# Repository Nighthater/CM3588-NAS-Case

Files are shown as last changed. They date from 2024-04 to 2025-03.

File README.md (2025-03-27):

# CM3588 NAS Case
3D Printable Case for the CM3588 NAS board.  
Minimal Assembly required.  
Variants for Installations with fans are included.

If you have a fan, you can use [this code by vijaygill](https://github.com/vijaygill/pwm-fan-cm3588) to control the fans

### NOTE:
I do not have the NAS Board on Hand. If you decide to print the Case, please leave me some feedback to further improve the Case.  

The Case is [available for download](https://github.com/Nighthater/CM3588-NAS-Case/tree/master/STL).

## Required Components
- 4 M2 Threaded inserts
- 4 M2 Flat-Head Screws

Any Flat-Head screw is ok. Contersunk screws will damage the PCB, so avoid using these.  
The screw length must be smaller than 10mm.  

## Assembly

1. You need the three Parts of the Case and 5 buttons printed.
2. Begin by inserting the Threaded inserts in the 4 Standoff holes in the Main Body.
3. Place the 5 buttons inside the holes.
4. Insert the CM3588 Board into the Case. Keep it level when inserting. It should go in freely until it hits the standoffs.
5. Secure the PCB with the 4 Screws.
6. Attach the two Panels. The Panels are only using a friction fit currently. This might me improved in later revisions.
7. The NAS is ready to power up.

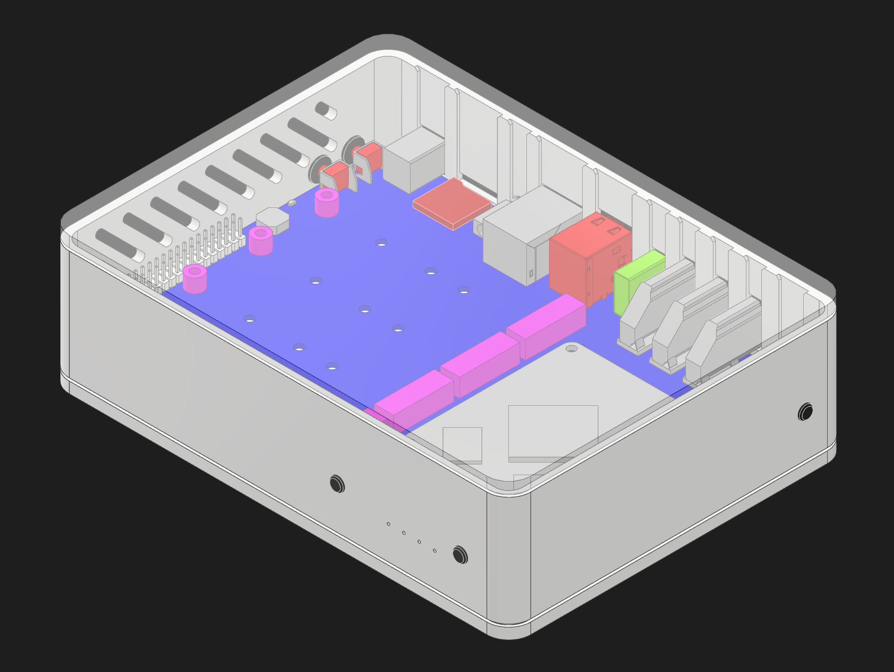
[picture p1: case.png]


## Internal Fan Variant
Also availible in a taller version with an internal fan. Uses a 80mm Noctua fan.
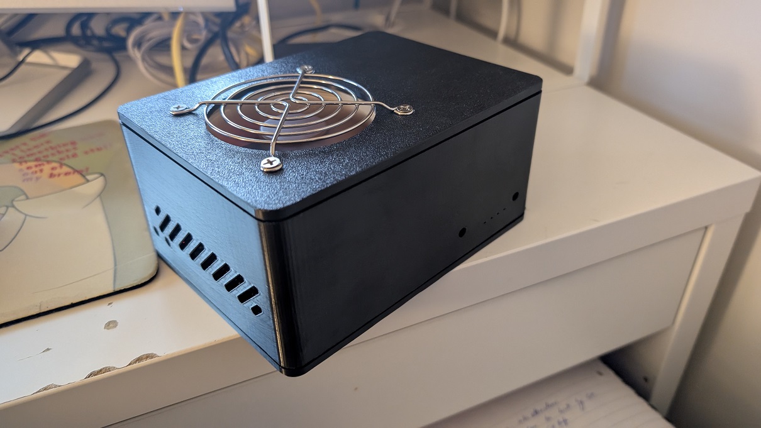
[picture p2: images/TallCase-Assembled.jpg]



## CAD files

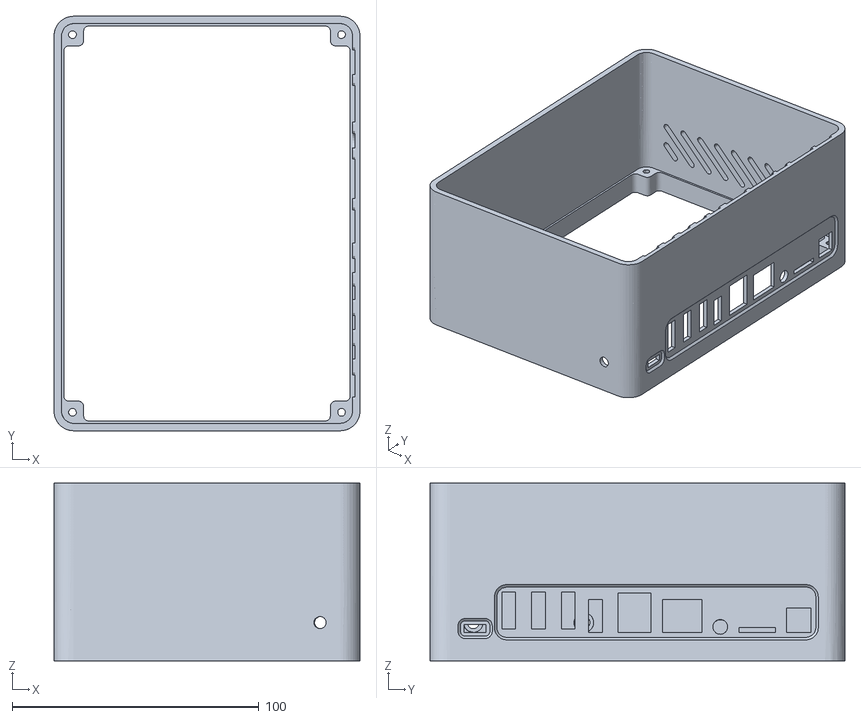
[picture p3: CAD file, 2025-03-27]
STL/MainBody - tall.stl
124.0 x 168.0 x 72.0

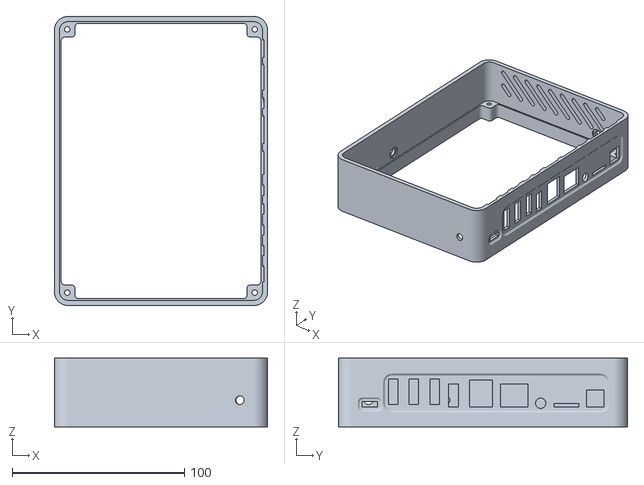
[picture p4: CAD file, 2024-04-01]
STL/MainBody.stl
124.0 x 168.0 x 40.0

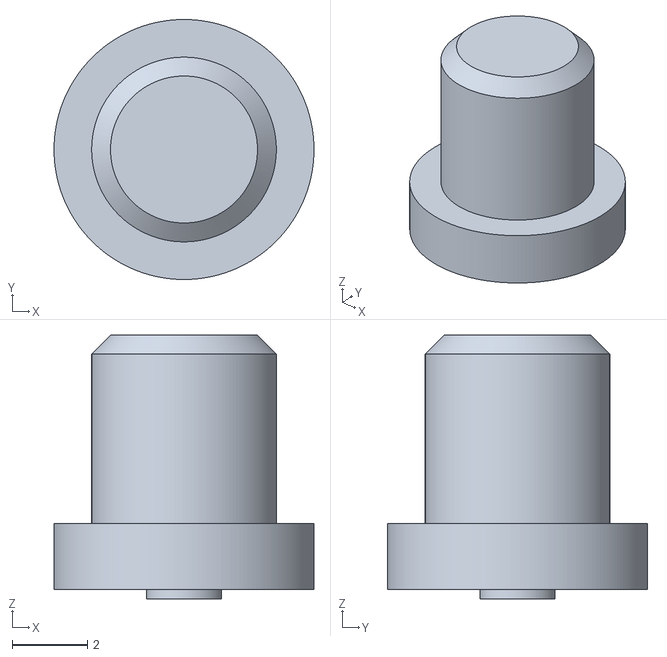
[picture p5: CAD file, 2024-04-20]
STL/Button.stl
6.90 x 6.90 x 7.00

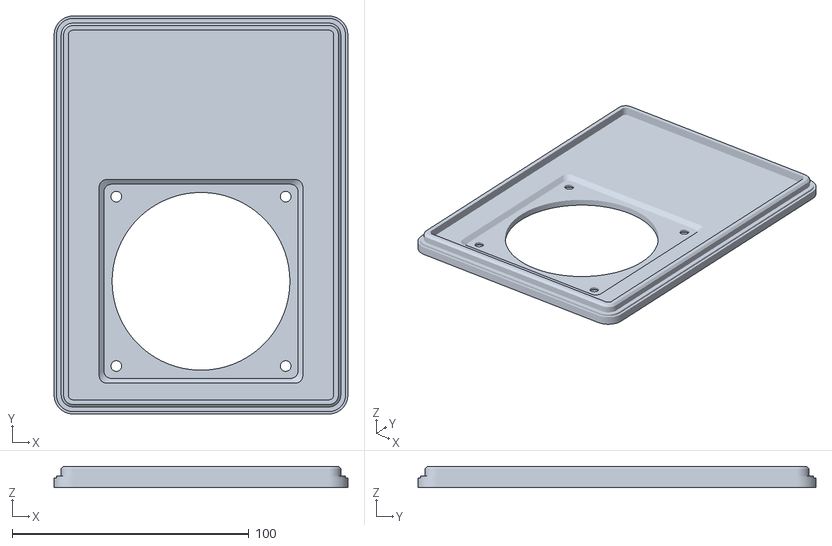
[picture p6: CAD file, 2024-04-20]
STL/TopShell_with_80mm_fan.stl
124.0 x 168.0 x 9.00

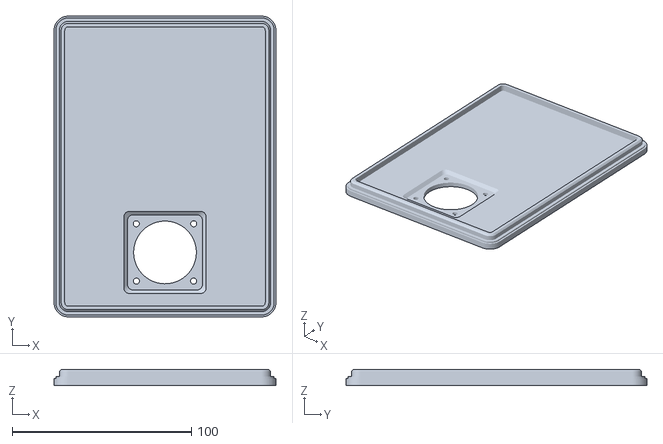
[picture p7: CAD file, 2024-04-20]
STL/TopShell_with_40mm_fan.stl
124.0 x 168.0 x 9.00

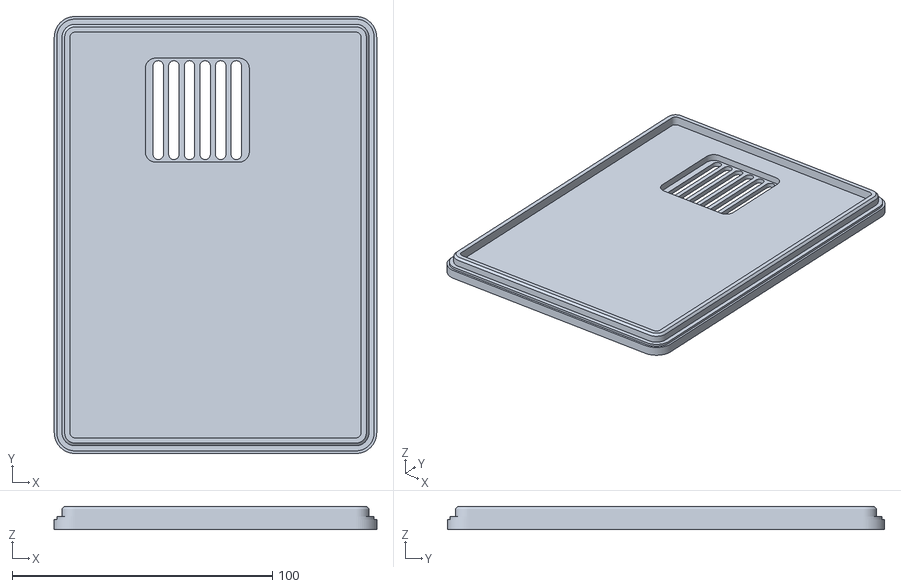
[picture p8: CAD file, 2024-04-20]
STL/TopShell_40mm_onboard_fan.stl
124.0 x 168.0 x 9.00

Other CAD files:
STL/TopShell.stl
STL/BottomShell.stl

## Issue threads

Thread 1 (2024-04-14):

Some adjustments

TurtleTony, 2024-04-14:
Hi there! First of all, thank you so much, the case is amazing :-) A friend of mine printed it for me with the following settings:

Printer: Anycubic Vyper
Slicer: Ultimaker Cura 5.2.2
Filament: Eryone White PLA 1,75 +- 0.03

0.16mm, 10% Infill, 200°C, 60.0mm/s

I've attached some pictures of how the board fits and firmly sits in the case. The screw-holes are somewhat misaligned, but I didn't even need the screws at all.

The slot for the sd card was a little too narrow so I had to sand it down a bit to get proper access to it. Otherwise all the I/O seems to be accessible to me.

An issue I had: The buttons don't work at all, they are a lot deeper than you'd think so they need to be at least 2mm longer to be able to use.

A feature idea: The heatsink has mounting holes for what I believe to be a 40mm fan, you could add an appropriate hole above this area to the lid, so that a fan could suck air from the lid and blow it out the side holes. I tried running the board cooled passively, but my SSDs got over 60 degree when utilized and had an idle temp of around 45-50°, that's not something to run 24/7 I feel like, so a fan hole would definitely add some more options.
Depending on the type of cable used, the case might benefit from slightly larger slots for the USB and HDMI connectors. Although sanding them down works too.

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

Nighthater, 2024-04-20:
Hi, thanks for the feedback. Glad that you like it so far.
I revised the Buttons and made them 2mm longer, they should be usable now.

The SD Card Reader Slot and the HDMI and USB ports are also now a bit bigger and should not require further sanding.

For the cooling issue, there are now three new lids. One with Holes to allow a 40mm fan mounted on the heatsink to pull in air.
The other two allow a 40mm or 80mm fan to be mounted directly on the lid.

TurtleTony, 2024-04-22:
Amazing! Thank you so much for the revisions! :-)
For cooling I actually went with laser-cutting a hole into the lid (but messed up and cut a square instead) so I mounted a fan to a glued on wood panel.

I will print the revised buttons and let you know how they work out :-)

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

mrjamesdoan, 2024-06-10:
I just came here to say thank you so much for creating this case. It works perfect for my needs and is very well designed. I'm impressed by the small details of the case and it seems to be better quality than the rest of available models out there. May I ask how you learned to design this? What tools did you use to design it and if you could point me to any resources that goes over how to design, specifically the rounded corners, indented inputs area, the raised mounts for the PCB and also the snap fit lids. It would be greatly appreciated!

Nighthater, 2024-06-11:
Hi, I'm glad you like the case. I made it with Autodesk Inventor, but you could design this case in probably any CAD Software you want (Fusion360 and OnShape are two popular free ones that come to mind).

I'm a mechanical engineer, so i've worked quite some time now with different CAD Software and how to design parts.
You can look at youtube tutorials and courses on how to use these CAD programs. Trying stuff out yourself is also important, even if its just a small simple part.

The snap fit lids are the same size and shape on both parts, just inside and outside, so its creating a transition fit.
For the design of the Case, I didn't really learn it how to do it i would say? It's more of creative process.
I tried to figure out how to build around the NAS Board itself while keeping all 4 sides accessible for the buttons and ports. That's why it's laid down from above, and that dictates the overall form of the case.
I also quite like the function first approach that Bauhaus Design takes (Rounded corners, straight lines, function over form). So theres an design style there you could look at.
Its also helpful for me to look at how different products are built from the inside in general. You can get lots of ideas to use in your own projects.

I hope i could help you, please feel free to ask if you have further questions.

Closed 2024-08-27.

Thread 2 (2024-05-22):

STL files and instructions dont seem to match

CyberGWJ, 2024-05-22:
I am looking for a case for the CM3588 and came across this design.  I like the overall design and assembly options.  Reading the instructions the MainBody.stl is missing some holes for buttons and heat inserts.  Or am I missing something.  Thanks.

Nighthater, 2024-05-29:
Sorry, my bad, thanks for noticing and opening an issue.
I seem to have uploaded a Version with some missing Elements. I just uploaded the corrected file.

Closed 2024-06-09.

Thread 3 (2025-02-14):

Thank you and a small help to review my change

vijaygill, 2025-02-14:
Hi,

Thanks for such a good design. I recently bought this board and I was looking for a nice case because the standard metallic one is useless.

I am planning to have 80mm noctua fan so I thought of raising the height of the MainBody a bit.

Now, I am sure I can take a perfect design and ruin it!

Can you please have a look at this STL file to see if there is any issue?

I will sending it for getting a case 3d printed for me.

Thanks.

Link to file - https://www.tinkercad.com/things/dHRowPkgcDf-cm3588-nas?sharecode=vswPMv-5Zv6E8PJubyTdc5Q0LR68vEA3aVKAgjTus_E

Pasting link to file since STL file cannot be attached with this issue.

Nighthater, 2025-02-16:
Hi,

I don't see any issues with your STL.
It should print just fine.

vijaygill, 2025-02-16:
> Hi,
>
> I don't see any issues with your STL. It should print just fine.

Thanks again! Order placed.

By the way, I have forked your project and added the file there - https://github.com/vijaygill/CM3588-NAS-Case

vijaygill, 2025-03-04:
@Nighthater

Just wanted to share the case I got delivered today...

Minor issue with the buttons - they do not slide freely but I can ignore it. This is going to be much better case than the one I have now!

Thanks for all the hard work!

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

vijaygill, 2025-03-21:
@Nighthater - sorry for harping on about this but I want to thank you again for such a nice piece of work.

I have created this repository for a small utility (a background service) to control the PWM fan in this NAS [https://github.com/vijaygill/pwm-fan-cm3588](https://github.com/vijaygill/pwm-fan-cm3588).

I hope it is of some use to you too.

It is successfully running on my setup.

Nighthater, 2025-03-27:
Hi, great addition, i added your repo as a link to my Readme.

If you want, you can also open a pull request from your fork so that your STL is on my repo as well.

vijaygill, 2025-03-27:
> Hi, great addition, i added your repo as a link to my Readme.
>
> If you want, you can also open a pull request from your fork so that your STL is on my repo as well.

Thank you! PR opened.

Closed 2025-02-16.

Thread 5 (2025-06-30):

IR receiver opening

sapradhan, 2025-06-30:
There is an IR receiver between user button and nvme LEDs. Please add an opening for it.

Thank you for the wonderful design

Nighthater, 2025-07-04:
Added the opening to both case variants.

Closed 2025-07-04.

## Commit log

2024-03-31 Prototype Sketch
2024-03-31 Added Sketch of NAS Case
2024-03-31 Updated the prototype render
2024-04-01 First Prototype
    [BottomShell.stl, Button.stl, MainBody.stl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]
2024-04-20 New Parts
    + Extended Button
    + Gave Ports more clearance
    + Added Top Shell Versions for Fan mountings
    [Button.stl, MainBody.stl, TopShell_40mm_onboard_fan.stl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]
2024-05-29 Fixed Main Body stl
    [MainBody.stl]
2024-06-03 Release
    Added Step File
    [BottomShell.stl, Button.stl, MainBody.stl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]
2025-02-16 Added MainBody - tall.stl
    [MainBody - tall.stl]
